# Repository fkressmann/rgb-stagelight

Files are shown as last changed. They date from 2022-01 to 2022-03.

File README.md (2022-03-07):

# High Power RGB LED control

I got my hands on some high power (~800W) RGB LED modules used in stage lightning applications.
Sadly, I just got the LED modules without any driver circuit (but luckily with the cooling units),
so I had to reverse-engineer all the electronic details.

There was one big LED chip (~8x8cm) per color with two times 44 LEDs in series. The three chips were
mounted on three sides of a prism-like mirror case which redirected the light all into one direction
using color-spectrum and angle-of-irradiation dependent mirrors. No idea if I explained this
correctly, I not a physicist :D Anyway, impressive engineering!

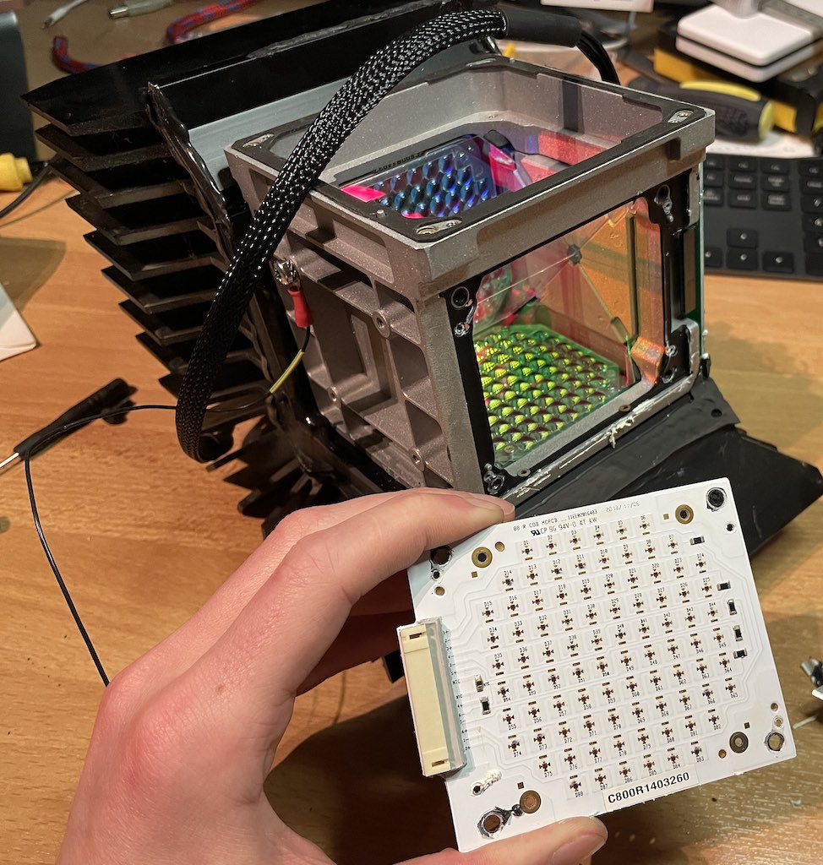
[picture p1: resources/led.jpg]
led chip, mirrors and heatsink


### 300V? What?

At 700mA forward current, one (green) LED took around 3.1V. For 44 LEd, this would sum up to ~140V.
As I didn't want to build / buy six drivers, I modified the PCB and put all the 88 LEDS in series.
Dang, now I need ~280V to drive them :D.

Luckily, there is Meanwell. To be precise, the `XLG-240-L-AB`. A (up to) 370V constant power
dimmable LED driver. Awesome! So I bought three of them.

### Cooling

So the only thing left was to build something PWM controlling the XLGs, right? Nope :D You cannot
put 800 Wats of power into an LED without cooling. Without active cooling. Thankfully, the LED
module already contained big heat sinks with PWM controllable 24V fans. And after some research, I
even found NTCs on every LED module. And nobody likes fan noise if you don't need it. So,
temperature dependant fan control, please!

### Control

But how to control the colors now? Web UI? DMX? Art-Net? All! Thankfully, there are already some
cool libs to talk to [DMX](https://github.com/someweisguy/esp_dmx)
and [Art-Net](https://github.com/rstephan/ArtnetWifi). Using those two libs, the system can even
translate Art-Net to DMX and vice versa. Always taking ch 1-3 as RGB input.

### Electronics

In the end, it looks like this: (Fritzing file included in `/resources`)

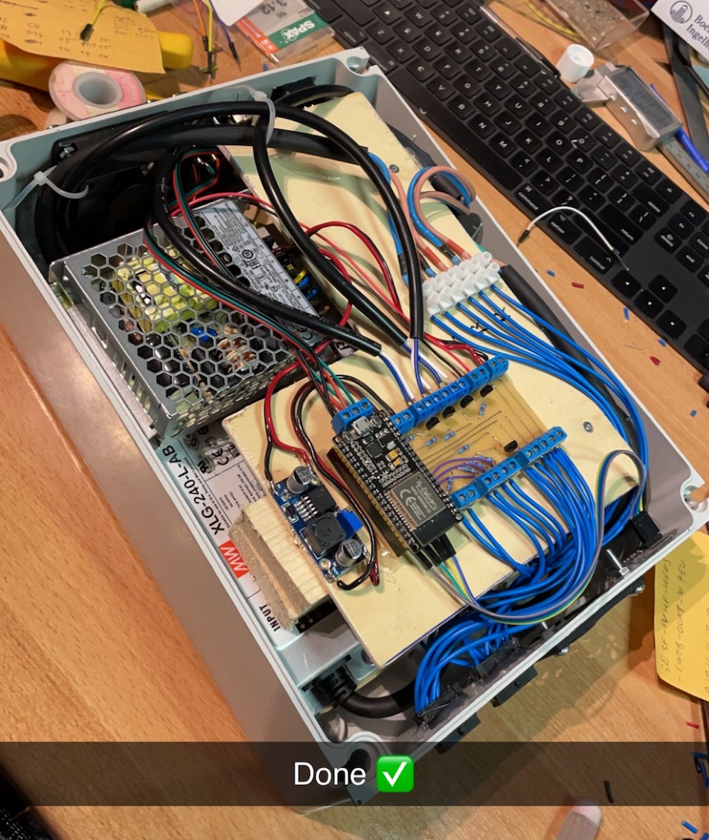
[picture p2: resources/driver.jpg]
driver


### Outlook

As the original stagelight is a moving head with gobos etc, this would be the next step. But I have
to wait until I get my hands on a broken one (with intact mechanics) to built that... Project for
another winter :)

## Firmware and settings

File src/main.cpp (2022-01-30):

#include "display.h"
#include "dmx.h"
#include "ota.h"
#include <Arduino.h>
#include <ArtnetWifi.h>
#include <ESPAsyncWebServer.h>
#include <ESPAsync_WiFiManager.h>

#define GPIO_LED_R 14
#define PWM_CHANNEL_R 0
#define GPIO_LED_G 12
#define PWM_CHANNEL_G 1
#define GPIO_LED_B 13
#define PWM_CHANNEL_B 2

#define GPIO_CASE_FAN 5
#define GPIO_FAN_OUT 25
#define PWM_CHANNEL_FAN_OUT 3
#define GPIO_FAN_1_IN 26
#define GPIO_FAN_2_IN 27

#define GPIO_TEMP_R 35
#define GPIO_TEMP_G 32
#define GPIO_TEMP_B 33
#define GPIO_TEMP_BOX 34

#define GPIO_SCL 22
#define GPIO_SDA 21

uint8_t Rval = 0;
uint8_t Gval = 0;
uint8_t Bval = 0;

uint8_t RvalActual = 0;
uint8_t GvalActual = 0;
uint8_t BvalActual = 0;

double tempFactor = 1;

uint8_t Rtemp = 0;
uint8_t Gtemp = 0;
uint8_t Btemp = 0;
uint8_t driverTemp = 0;

uint16_t fanCounter1 = 0;
uint16_t fanCounter2 = 0;
ulong fanTimer = 0;

ulong tempTimer = 0;

boolean modeArtNet = true;

AsyncWebServer webServer(80);
DNSServer dnsServer;

ArtnetWifi artnet;
const int startUniverse = 0; // CHANGE FOR YOUR SETUP most software this is 1, some software send out artnet first universe as 0.

// Check if we got all universes
const int maxUniverses = 1;
bool universesReceived[maxUniverses];
bool sendFrame = 1;
int previousDataLength = 0;

const char index_html[] PROGMEM = R"rawliteral(
<!DOCTYPE HTML><html><head>
  <title>G-Spot Control</title>
  <meta name="viewport" content="width=device-width, initial-scale=1">
  <script src="https://ajax.googleapis.com/ajax/libs/jquery/1.11.0/jquery.min.js"></script>
  </head><body>
  <h2>Farben</h2>
  <form action="/color" method="post">
  <label for="color">Select color:</label>
  <input type="color" id="color" name="color" value="#%color%">
  </form><hr>
  <form action="/text" method="post">
  <label for="t">Text to display:</label>
  <textarea name="t" rows="3" cols="30"></textarea>
  <input type="submit" value="Speichern">
  </form><hr>
  <form action="/mode" method="post">
  <label for="mode">Mode:</label>
  <select name="mode" id="mode">
    <option value="art-net" %art-net-selected%>Art-Net</option>
    <option value="dmx" %dmx-selected%>DMX</option>
  </select>
  <input type="submit" value="Speichern">
  </form><hr>
</body>
<script>
    $(document).ready(function(e) {
        $("[name='color']").on('change', function() {
            var url = "/color";
            $.ajax({
                type: "POST",
                url: url,
                data: $("#color").serialize()
            });
        });
    });
</script></html>)rawliteral";

// Replaces placeholder in HTML
String processor(const String &var) {
  if (var == "color") {
    char dataString[7] = {0};
    sprintf(dataString, "%02X%02X%02X", Rval, Gval, Bval);
    return String(dataString);
  }
  if (var == "art-net-selected" && modeArtNet) {
    return "selected";
  }
  if (var == "dmx-selected" && !modeArtNet) {
    return "selected";
  }
  return String();
}

uint8_t hexStrToInt(const char str[]) {
  return (uint8_t)strtol(str, 0, 16);
}

void writeToPwm() {
  if (tempFactor == 1 && Rval == RvalActual && Gval == GvalActual && Bval == BvalActual) {
    return;
  }
  RvalActual = tempFactor * Rval;
  GvalActual = tempFactor * Gval;
  BvalActual = tempFactor * Bval;
  ledcWrite(PWM_CHANNEL_R, 255 - RvalActual);
  ledcWrite(PWM_CHANNEL_G, 255 - GvalActual);
  ledcWrite(PWM_CHANNEL_B, 255 - BvalActual);
  displayRGBIntensity(RvalActual, GvalActual, BvalActual);
}

void decodeAndUpdateColor(String colorString) {
  Rval = hexStrToInt(colorString.substring(1, 3).c_str());
  Gval = hexStrToInt(colorString.substring(3, 5).c_str());
  Bval = hexStrToInt(colorString.substring(5).c_str());
}

void onArtNetFrame(uint16_t universe, uint16_t length, uint8_t sequence, uint8_t *data) {
  if (universe == 0) {
    sendDmxFrame(length, data);
    if (length > 2) {
      Rval = data[0];
      Gval = data[1];
      Bval = data[2];
    }
  }
}

void onDmxFrame(uint16_t length, uint8_t *data) {
  // First Byte is DMX packet type, 0 is dimmer
  if (data[0] == 0 && length > 3) {
    Rval = data[1];
    Gval = data[2];
    Bval = data[3];
    memcpy(artnet.artnetPacket, data + 1, length - 1);
    artnet.write();
  }
}

void IRAM_ATTR isrFan1() {
  fanCounter1 += 1;
}

void IRAM_ATTR isrFan2() {
  fanCounter2 += 1;
}

void setup() {
  // put your setup code here, to run once:
  Serial.begin(115200);
  while (!Serial)
    ;
  delay(200);

  ledcSetup(PWM_CHANNEL_R, 1000, 8);
  ledcAttachPin(GPIO_LED_R, PWM_CHANNEL_R);
  ledcWrite(PWM_CHANNEL_R, 255);

  ledcSetup(PWM_CHANNEL_G, 1000, 8);
  ledcAttachPin(GPIO_LED_G, PWM_CHANNEL_G);
  ledcWrite(PWM_CHANNEL_G, 255);

  ledcSetup(PWM_CHANNEL_B, 1000, 8);
  ledcAttachPin(GPIO_LED_B, PWM_CHANNEL_B);
  ledcWrite(PWM_CHANNEL_B, 255);

  pinMode(GPIO_CASE_FAN, OUTPUT);
  digitalWrite(GPIO_CASE_FAN, LOW);

  ledcSetup(PWM_CHANNEL_FAN_OUT, 1000, 8);
  ledcAttachPin(GPIO_FAN_OUT, PWM_CHANNEL_FAN_OUT);

  pinMode(GPIO_FAN_1_IN, INPUT_PULLUP);
  attachInterrupt(GPIO_FAN_1_IN, isrFan1, FALLING);

  pinMode(GPIO_FAN_2_IN, INPUT_PULLUP);
  attachInterrupt(GPIO_FAN_2_IN, isrFan2, FALLING);

  setupDisplay();

  Serial.print("\nStarting Async_AutoConnect_ESP8266_minimal on " + String(ARDUINO_BOARD));
  Serial.println(ESP_ASYNC_WIFIMANAGER_VERSION);
  ESPAsync_WiFiManager ESPAsync_wifiManager(&webServer, &dnsServer, "AutoConnectAP");
  ESPAsync_wifiManager.autoConnect("AutoConnectAP");
  if (WiFi.status() == WL_CONNECTED) {
    Serial.print(F("Connected. Local IP: "));
    Serial.println(WiFi.localIP());
    displayWiFi(WiFi.SSID(), WiFi.localIP());
  } else {
    Serial.println(ESPAsync_wifiManager.getStatus(WiFi.status()));
  }

  setupOta();

  artnet.begin();
  artnet.setArtDmxCallback(onArtNetFrame);
  setupDmxDefaultTx(onDmxFrame);
  displayInfo("Mode Art-Net -> DMX");

  webServer.on("/", HTTP_GET, [](AsyncWebServerRequest *request) {
    request->send_P(200, "text/html", index_html, processor);
  });

  webServer.on("/color", HTTP_POST, [](AsyncWebServerRequest *request) {
    if (request->hasParam("color", true)) {
      String value = request->getParam("color", true)->value();
      decodeAndUpdateColor(value);
    }
    request->send(200);
  });

  webServer.on("/text", HTTP_POST, [](AsyncWebServerRequest *request) {
    if (request->hasParam("t", true)) {
      String value = request->getParam("t", true)->value();
      displayInfo(value);
    }
    request->redirect("/");
  });

  webServer.on("/mode", HTTP_POST, [](AsyncWebServerRequest *request) {
    if (request->hasParam("mode", true)) {
      String value = request->getParam("mode", true)->value();
      if (value.equals("art-net")) {
        artnet.begin();
        dmxSwitchToTx();
        displayInfo("Mode Art-Net -> DMX");
        modeArtNet = true;
      } else if (value.equals("dmx")) {
        dmxSwitchToRx();
        displayInfo("Mode DMX -> Art-Net");
        modeArtNet = false;
      }
    }
    request->redirect("/");
  });

  webServer.begin();
}

uint8_t tempRead(uint8_t pin) {
  uint32_t adc = 0;
  for (int i = 0; i < 100; i++) {
    adc += analogRead(pin);
  }
  adc /= 100;
  double voltage = ((3.3 / 4096) * adc) + 0.155;
  double resistance = ((3.3 - voltage) * 10000) / voltage;
  uint8_t temp = round((1 / ((log(resistance / 10000) / 3977) + (1 / (25 + 273.15)))) - 273.15);
  return temp;
}

void setFanSpeed(uint8_t percent) {
  percent = min((uint8_t)100, percent);
  percent = max((uint8_t)0, percent);
  ledcWrite(PWM_CHANNEL_FAN_OUT, 255 - (percent * 2.55));
}

void tempToFanSpeed(uint8_t maxTemp) {
  if (maxTemp > 30) {
    setFanSpeed((maxTemp - 30) * 5);
  } else {
    setFanSpeed(0);
  }
}

// ToDo: Fix overshoot
void tempToTempFactor(uint8_t maxTemp) {
  if (maxTemp > 50) {
    tempFactor = 1.0 - ((double)(min((uint8_t)70, maxTemp) - 50) / 20);
  } else {
    tempFactor = 1.0;
  }
}

void handleTemp() {
  ulong timeframe = millis() - tempTimer;
  if (timeframe > 1234) {
    uint8_t tR = tempRead(GPIO_TEMP_R);
    uint8_t tG = tempRead(GPIO_TEMP_G);
    uint8_t tB = tempRead(GPIO_TEMP_B);
    uint8_t tCase = tempRead(GPIO_TEMP_BOX);
    if (tCase > 35) {
      digitalWrite(GPIO_CASE_FAN, HIGH);
    } else {
      digitalWrite(GPIO_CASE_FAN, LOW);
    }
    uint8_t maxLedTemp = max(tR, max(tG, tB));
    tempToFanSpeed(maxLedTemp);
    tempToTempFactor(maxLedTemp);
    displayTemp(tR, tG, tB, tCase);
    tempTimer = millis();
  }
}

void readFanSpeed() {
  ulong timeframe = millis() - fanTimer;
  if (timeframe > 999) {
    uint16_t fanSpeed1 = ((double)fanCounter1 / timeframe) * 30000;
    uint16_t fanSpeed2 = ((double)fanCounter2 / timeframe) * 30000;
    displayFanSpeed(fanSpeed1, fanSpeed2);
    fanCounter1 = 0;
    fanCounter2 = 0;
    fanTimer = millis();
  }
}

void loop() {
  ArduinoOTA.handle();

  handleTemp();
  readFanSpeed();

  if (modeArtNet) {
    artnet.read();
  } else {
    handleDmxRx();
  }
  writeToPwm();
  updateDisplay();
}

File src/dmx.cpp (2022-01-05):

#include "dmx.h"

int transmitPin = 17;
int receivePin = 16;
int enablePin = 21;

boolean rxActive = false;
boolean txActive = false;
boolean initialized = false;

dmx_port_t dmxPort = 2;

byte data[DMX_MAX_PACKET_SIZE];

QueueHandle_t queue;

unsigned int timer = 0;
bool dmxIsConnected = false;

void (*dmxRxCallback)(uint16_t length, uint8_t *data);

void setupDmx() {
}

void setupDmxDefaultTx(void (*rxCallback)(uint16_t length, uint8_t *data)) {
  dmx_config_t dmxConfig = DMX_DEFAULT_CONFIG;
  dmx_param_config(dmxPort, &dmxConfig);
  dmx_set_pin(dmxPort, transmitPin, receivePin, enablePin);

  int queueSize = 1;
  int interruptPriority = 1;
  dmx_driver_install(dmxPort, DMX_MAX_PACKET_SIZE, queueSize, &queue,
                     interruptPriority);
  txActive = true;
  dmx_set_mode(dmxPort, DMX_MODE_TX);
  dmxRxCallback = rxCallback;
  rxActive = false;
}

void dmxSwitchToRx() {
  txActive = false;
  dmx_set_mode(dmxPort, DMX_MODE_RX);
  rxActive = true;
}

void dmxSwitchToTx() {
  rxActive = false;
  dmx_set_mode(dmxPort, DMX_MODE_TX);
  txActive = true;
}

// Handle incoming DMX packet and forward to callback
void handleDmxRxInternal() {
  dmx_event_t packet;

  if (xQueueReceive(queue, &packet, 0)) {
    /* If this code gets called, it means we've recieved DMX data! */

    /* We should check to make sure that there weren't any DMX errors. */
    if (packet.status == DMX_OK) {

      /* If this is the first DMX data we've received, lets log it! */
      if (!dmxIsConnected) {
        Serial.println("DMX connected!");
        displayInfo2("DMX connected");
        dmxIsConnected = true;
      }

      /* We can read the DMX data into our buffer and increment our timer. */
      dmx_read_packet(dmxPort, data, packet.size);
      timer += packet.duration;

      dmxRxCallback(packet.size, data + 1);

      /* Print a log message every 1 second (1,000,000 microseconds). */
      if (timer >= 1000000) {
        /* Print the received start code - it's usually 0.*/
        Serial.printf("Start code is 0x%02X and slot 1 is 0x%02X\n",
                      data[0], data[1]);
        timer -= 1000000;
      }
    } else {
      /* Uh-oh! Something went wrong receiving DMX. */
      Serial.println("DMX error!");
      displayInfo2("DMX error!");
    }
  } else {
    // Serial.println("No DMX package available");
  }
}

void handleDmxRx() {
  if (rxActive) {
    handleDmxRxInternal();
  }
}

void sendDmxFrame(uint16_t length, uint8_t *data) {
  // Crop frames to remove trailing 0 data
  // for (int i = length - 1; i >= 0; i--) {
  //   if (data[i]) {
  //     length = i + 1;
  //     break;
  //   }
  // }
  dmx_write_packet(dmxPort, data, length);
  // Wait for bus to be free before attempting to send data to avoid collisisons
  dmx_wait_tx_done(dmxPort, DMX_TX_PACKET_TOUT_TICK);
  dmx_tx_packet(dmxPort);
}

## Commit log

2021-12-23 Fan v1
2021-12-24 Fan speed fix
2022-01-02 Add Case Fan
2022-01-05 Adjust to real board, small fixes
    [dmx.cpp, main.cpp]
2022-03-07 Add fritzing file
    [led-controller.fzz]
